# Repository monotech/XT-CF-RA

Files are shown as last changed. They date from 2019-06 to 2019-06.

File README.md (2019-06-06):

Monotech XT-CF Rev1.0 ReadMe
----------------------------

8-bit ISA CompactFlash interface + Boot ROM (two separate functions that can be used individually).

Documentation for the switches can be found on the rear silkscreen.

Credit:
-------
Design uses schematic from Sergey Kiselev, with a few small changes to switches, 32K ROM support, and PCB from scratch to suit my brackets.\
www.malinov.com/Home/sergeys-projects/xt-cf-lite

XT-IDE Universal BIOS\
www.xtideuniversalbios.org  
www.xtideuniversalbios.org/binaries  
Use the latest working binary that includes XTIDECFG.COM (config utility), ide_xt.bin (8086/8088), ide_xtp.bin (80186/V20/V30 and up).

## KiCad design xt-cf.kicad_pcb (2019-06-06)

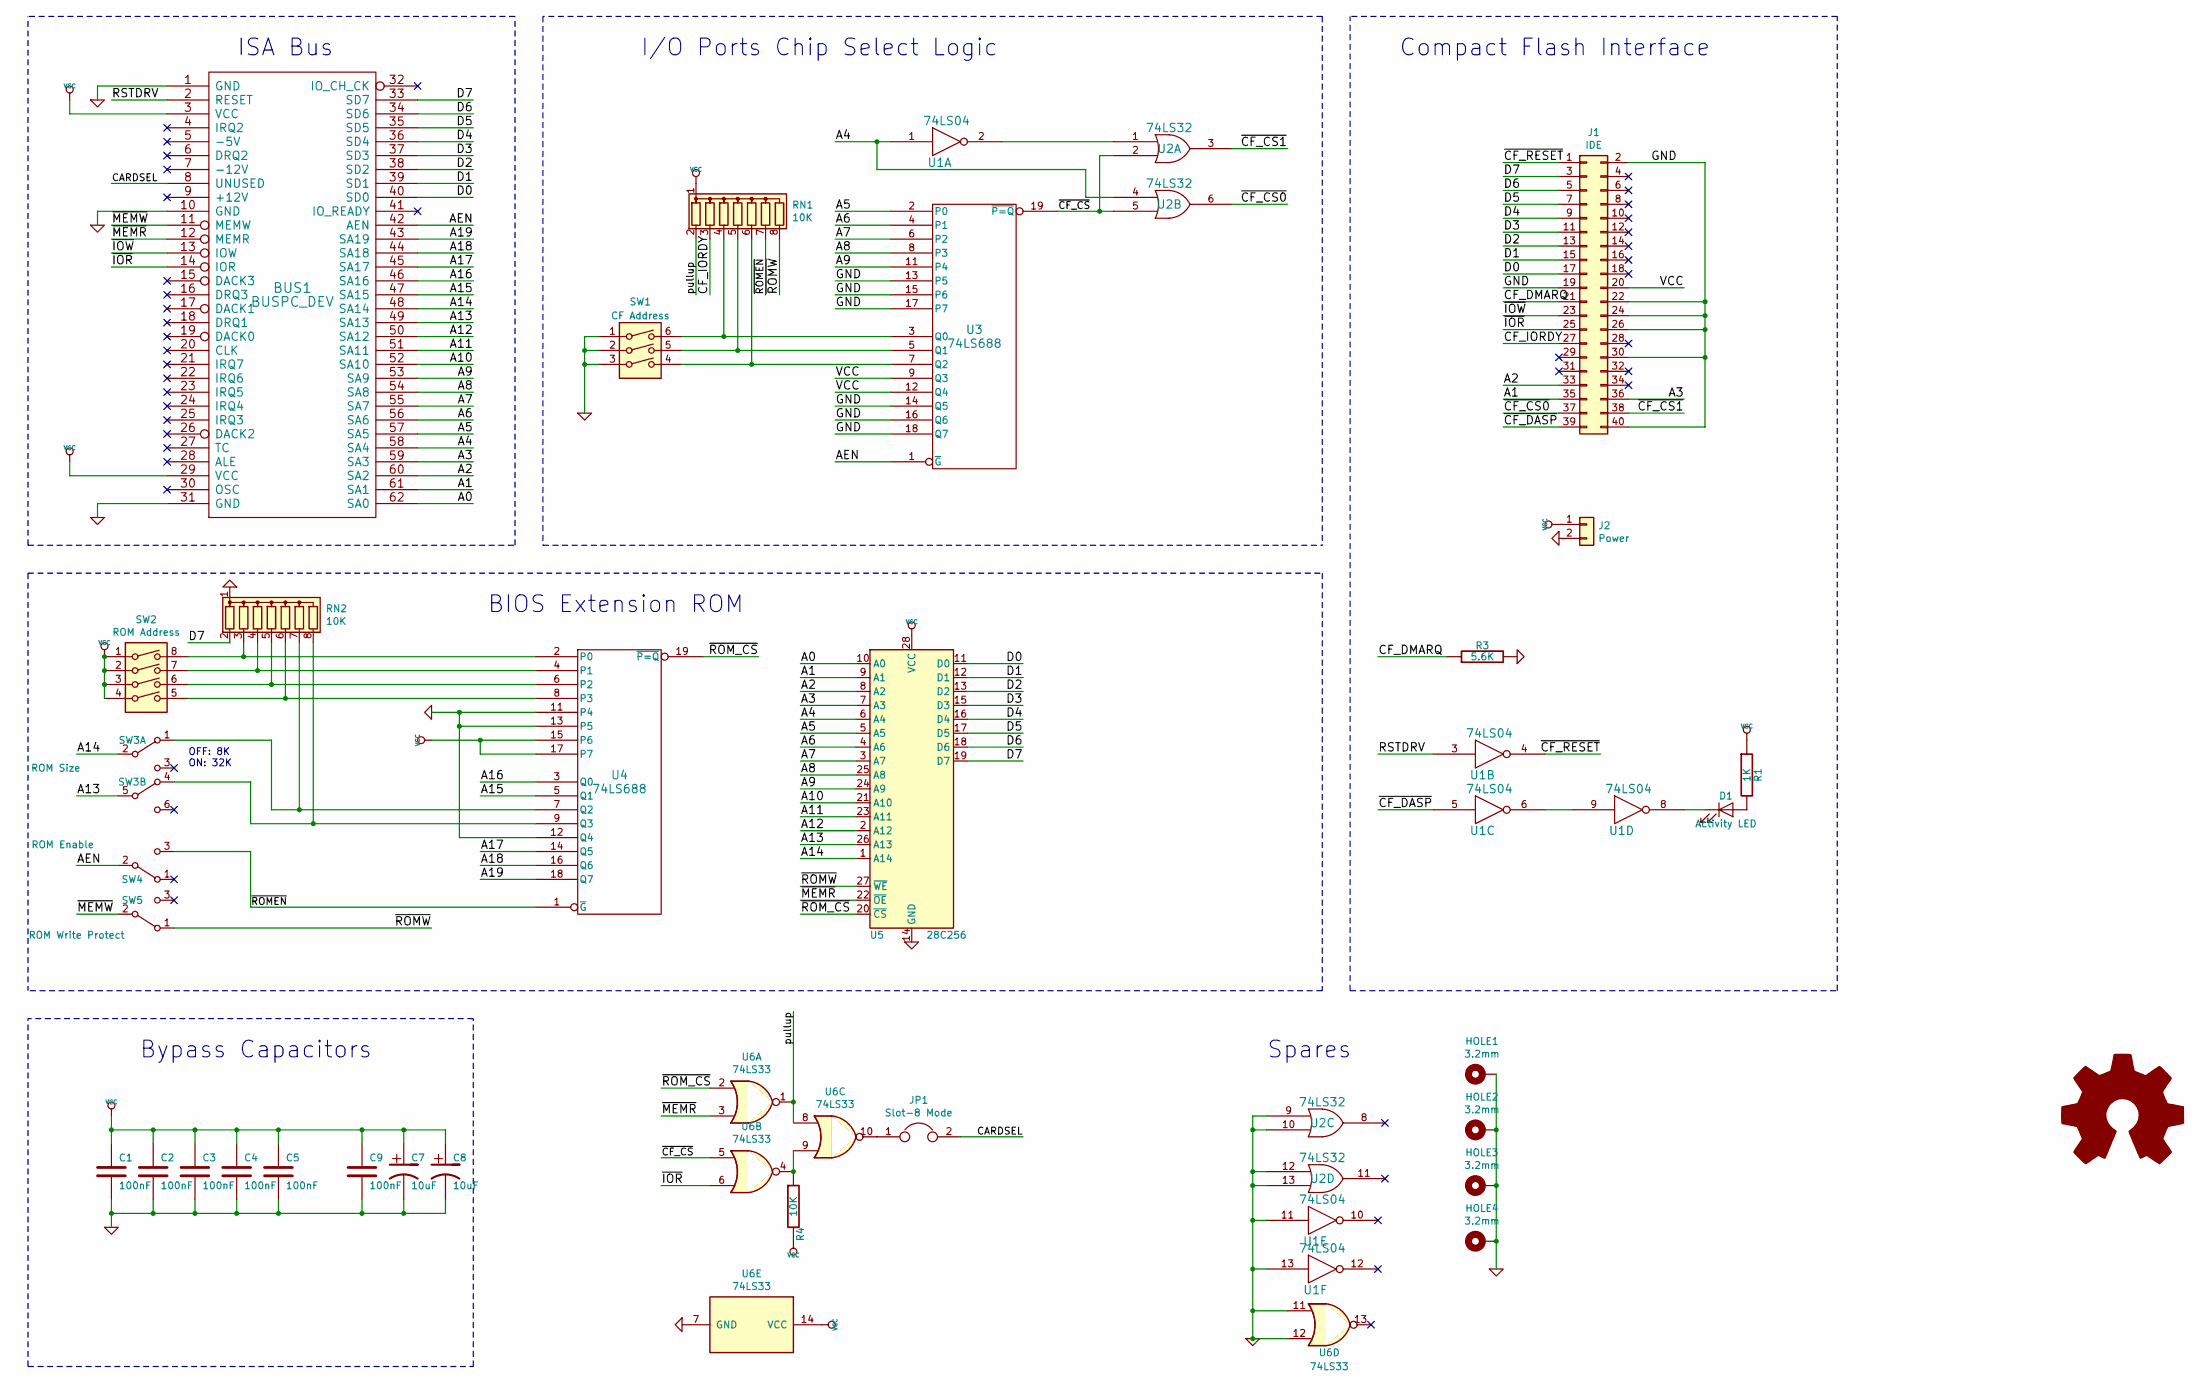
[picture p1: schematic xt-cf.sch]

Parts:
BUS1: BUSPC_DEV; ISA-8BIT-XT-CF
C1, C2, C3, C4, C5: 100nF; C_Disc_D4.3mm_W1.9mm_P5.00mm
C7, C8: 10uF; C_Disc_D4.3mm_W1.9mm_P5.00mm
C9: 100nF; C_0805_2012Metric_Pad1.15x1.40mm_HandSolder
D1: Activity LED; PinHeader_1x02_P2.54mm_Horizontal
HOLE1, HOLE2, HOLE3, HOLE4: 3.2mm; MountingHole_3.2mm_M3_Pad
J1: IDE; PinSocket_2x20_P2.54mm_Vertical
J2: Power; PinSocket_1x02_P2.54mm_Vertical
JP1: Slot-8 Mode; PinHeader_1x02_P2.54mm_Vertical
LOGO1: Logo_Open_Hardware_Large; Monotech Logo 12.7mm
R1: 1K; R_Axial_DIN0204_L3.6mm_D1.6mm_P5.08mm_Horizontal
R3: 5.6K; R_Axial_DIN0204_L3.6mm_D1.6mm_P5.08mm_Horizontal
R4: 10K; R_0805_2012Metric_Pad1.15x1.40mm_HandSolder
RN1, RN2: 10K; R_Array_SIP8
SW1: CF Address; SW_DIP_SPSTx03_Slide_9.78x9.8mm_W7.62mm_P2.54mm
SW2: ROM Address; SW_DIP_SPSTx04_Slide_9.78x12.34mm_W7.62mm_P2.54mm
SW3: ROM Size; SW_MS-22D18G2
SW4: ROM Enable; SW_CuK_OS102011MA1QN1_SPDT_Angled
SW5: ROM Write Protect; SW_CuK_OS102011MA1QN1_SPDT_Angled
U1: 74LS04; DIP-14_W7.62mm
U2: 74LS32; DIP-14_W7.62mm
U3, U4: 74LS688; DIP-20_W7.62mm
U5: 28C256; DIP-28_W15.24mm_Socket
U6: 74LS33; SOIC-14_3.9x8.7mm_P1.27mm

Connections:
/A0: BUS1.62 (SA0), U5.10 (A0)
/A1: BUS1.61 (SA1), J1.35, U5.9 (A1)
/A2: BUS1.60 (SA2), J1.33, U5.8 (A2)
/A3: BUS1.59 (SA3), J1.36, U5.7 (A3)
/A4: BUS1.58 (SA4), U1.1, U2.4, U5.6 (A4)
/A5: BUS1.57 (SA5), U3.2 (P0), U5.5 (A5)
/A6: BUS1.56 (SA6), U3.4 (P1), U5.4 (A6)
/A7: BUS1.55 (SA7), U3.6 (P2), U5.3 (A7)
/A8: BUS1.54 (SA8), U3.8 (P3), U5.25 (A8)
/A9: BUS1.53 (SA9), U3.11 (P4), U5.24 (A9)
/A10: BUS1.52 (SA10), U5.21 (A10)
/A11: BUS1.51 (SA11), U5.23 (A11)
/A12: BUS1.50 (SA12), U5.2 (A12)
/A13: BUS1.49 (SA13), SW3.5 (B), U5.26 (A13)
/A14: BUS1.48 (SA14), SW3.2 (B), U5.1 (A14)
/A15: BUS1.47 (SA15), U4.5 (Q1)
/A16: BUS1.46 (SA16), U4.3 (Q0)
/A17: BUS1.45 (SA17), U4.14 (Q5)
/A18: BUS1.44 (SA18), U4.16 (Q6)
/A19: BUS1.43 (SA19), U4.18 (Q7)
/AEN: BUS1.42 (AEN), SW4.2 (B), U3.1 (~G)
/CARDSEL: BUS1.8 (UNUSED), JP1.2
/CF_DMARQ: J1.21, R3.1
/CF_IORDY: J1.27, RN1.3 (R2)
/D0: BUS1.40 (SD0), J1.17, U5.11 (D0)
/D1: BUS1.39 (SD1), J1.15, U5.12 (D1)
/D2: BUS1.38 (SD2), J1.13, U5.13 (D2)
/D3: BUS1.37 (SD3), J1.11, U5.15 (D3)
/D4: BUS1.36 (SD4), J1.9, U5.16 (D4)
/D5: BUS1.35 (SD5), J1.7, U5.17 (D5)
/D6: BUS1.34 (SD6), J1.5, U5.18 (D6)
/D7: BUS1.33 (SD7), J1.3, RN2.2 (R1), U5.19 (D7)
/RSTDRV: BUS1.2 (RESET), U1.3
/pullup: RN1.2 (R1), U6.1, U6.8
/~CF_CS: U2.2, U2.5, U3.19 (~P=Q), U6.5
/~CF_CS0: J1.37, U2.6
/~CF_CS1: J1.38, U2.3
/~CF_DASP: J1.39, U1.5
/~CF_RESET: J1.1, U1.4
/~IOR: BUS1.14 (IOR), J1.25, U6.6
/~IOW: BUS1.13 (IOW), J1.23
/~MEMR: BUS1.12 (MEMR), U5.22 (~OE), U6.3
/~MEMW: BUS1.11 (MEMW), SW5.2 (B)
/~ROMEN: RN1.7 (R6), SW4.3 (C), U4.1 (~G)
/~ROMW: RN1.8 (R7), SW5.1 (A), U5.27 (~WE)
/~ROM_CS: U4.19 (~P=Q), U5.20 (~CS), U6.2
GND: BUS1.1 (GND), BUS1.10 (GND), BUS1.31 (GND), C1.2, C2.2, C3.2, C4.2, C5.2, C7.2, C8.2, C9.2, HOLE1.1, HOLE2.1, HOLE3.1, HOLE4.1, J1.2, J1.19, J1.22, J1.24, J1.26, J1.30, J1.40, J2.2, R3.2, RN2.1 (common), SW1.1, SW1.2, SW1.3, U1.7 (GND), U1.11, U1.13, U2.7 (GND), U2.9, U2.10, U2.12, U2.13, U3.10 (GND), U3.13 (P5), U3.14 (Q5), U3.15 (P6), U3.16 (Q6), U3.17 (P7), U3.18 (Q7), U4.10 (GND), U4.11 (P4), U4.12 (Q4), U4.13 (P5), U5.14 (GND), U6.7 (GND), U6.11, U6.12
unnamed: D1.1 (K), U1.8
unnamed: D1.2 (A), R1.2
unnamed: JP1.1, U6.10
unnamed: R4.1, U6.4, U6.9
unnamed: RN1.4 (R3), SW1.6, U3.3 (Q0)
unnamed: RN1.5 (R4), SW1.5, U3.5 (Q1)
unnamed: RN1.6 (R5), SW1.4, U3.7 (Q2)
unnamed: RN2.3 (R2), SW2.8, U4.2 (P0)
unnamed: RN2.4 (R3), SW2.7, U4.4 (P1)
unnamed: RN2.5 (R4), SW2.6, U4.6 (P2)
unnamed: RN2.6 (R5), SW2.5, U4.8 (P3)
unnamed: RN2.7 (R6), SW3.1 (A), U4.7 (Q2)
unnamed: RN2.8 (R7), SW3.4 (A), U4.9 (Q3)
unnamed: U1.2, U2.1
unnamed: U1.6, U1.9
VCC: BUS1.3 (VCC), BUS1.29 (VCC), C1.1, C2.1, C3.1, C4.1, C5.1, C7.1, C8.1, C9.1, J1.20, J2.1, R1.1, R4.2, RN1.1 (common), SW2.1, SW2.2, SW2.3, SW2.4, U1.14 (VCC), U2.14 (VCC), U3.9 (Q3), U3.12 (Q4), U3.20 (VCC), U4.15 (P6), U4.17 (P7), U4.20 (VCC), U5.28 (VCC), U6.14 (VCC)

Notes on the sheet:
Spares
ISA Bus
BIOS Extension ROM
Bypass Capacitors
I/O Ports Chip Select Logic
Compact Flash Interface
OFF: 8K ON: 32K

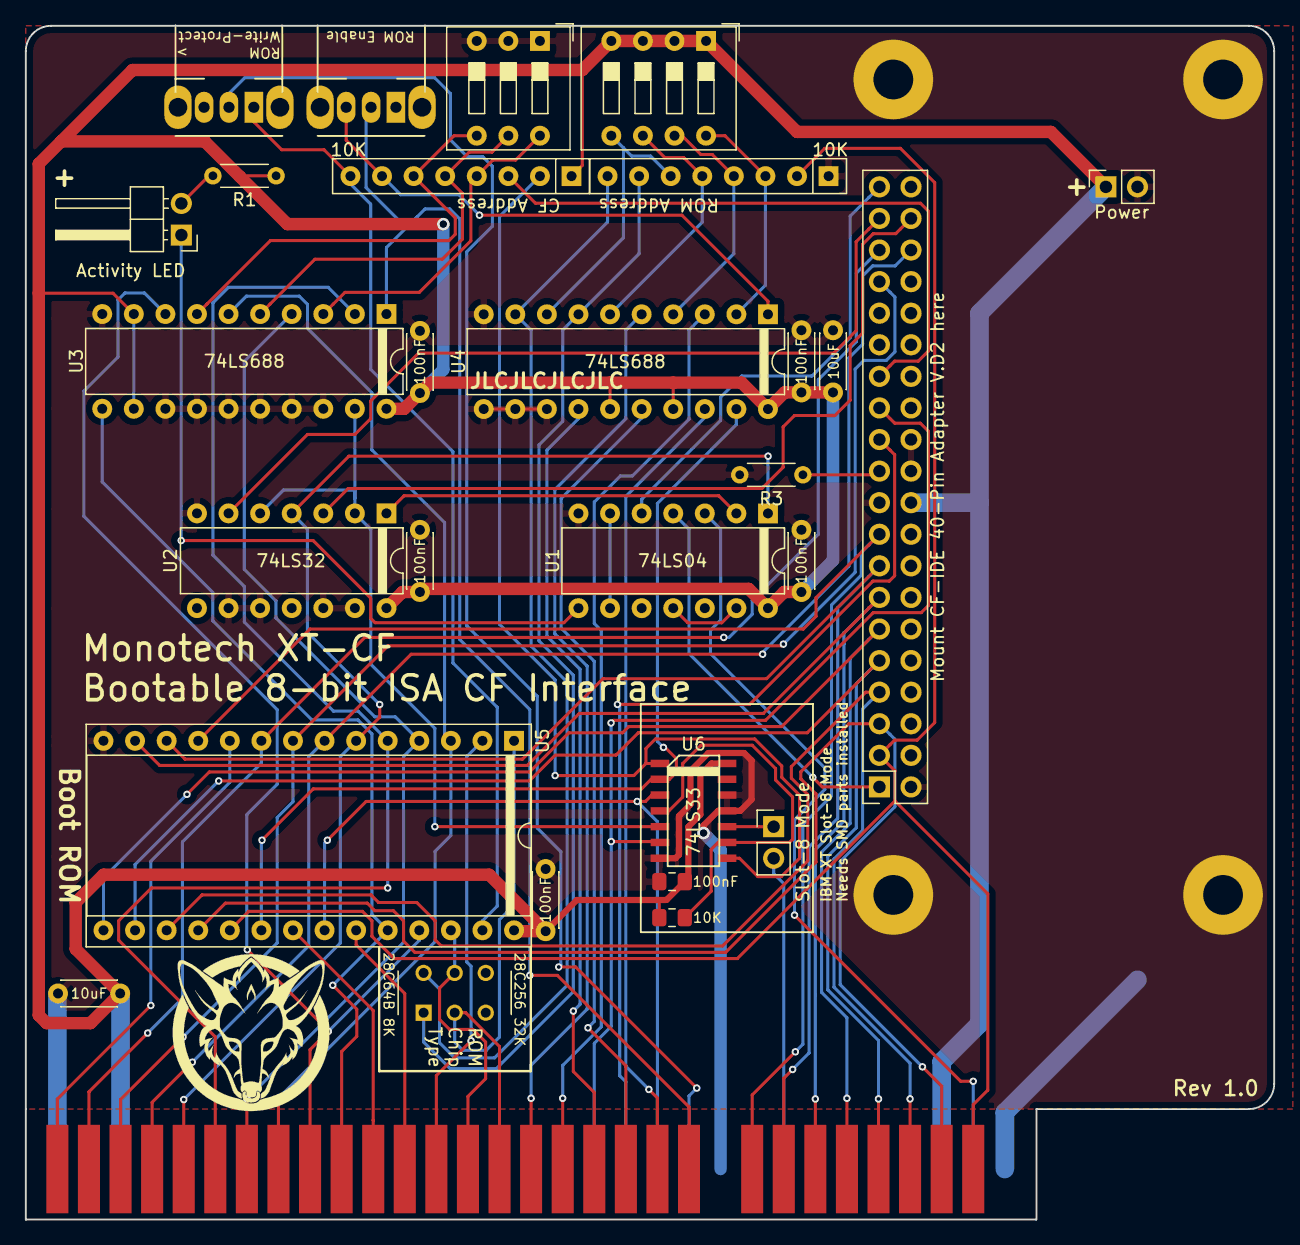
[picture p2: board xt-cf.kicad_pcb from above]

Board: 2 copper layers, 100.4 x 96.0 mm, 34 parts (0 on the bottom side), 63 nets.

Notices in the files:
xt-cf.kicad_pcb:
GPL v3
